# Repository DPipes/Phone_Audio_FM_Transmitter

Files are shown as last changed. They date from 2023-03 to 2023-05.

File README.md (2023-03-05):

# Phone Audio FM Transmitter

A device that connects to a smartphone over Bluetooth and transmits the phone's audio over FM. This allows users to listen to their phones over the radio of cars that do not otherwise offer that functionality. In contrast to similar devices on the market, this can scan the FM band and identify an open channel to broadcast on so the user only has to set their car radio to the same station.

This is an electrical engineering senior design project for ECE 445 at the University of Illinois - Urbana Champaign

Team Members:
 - James W.
 - Madigan C.
 - Dan P.

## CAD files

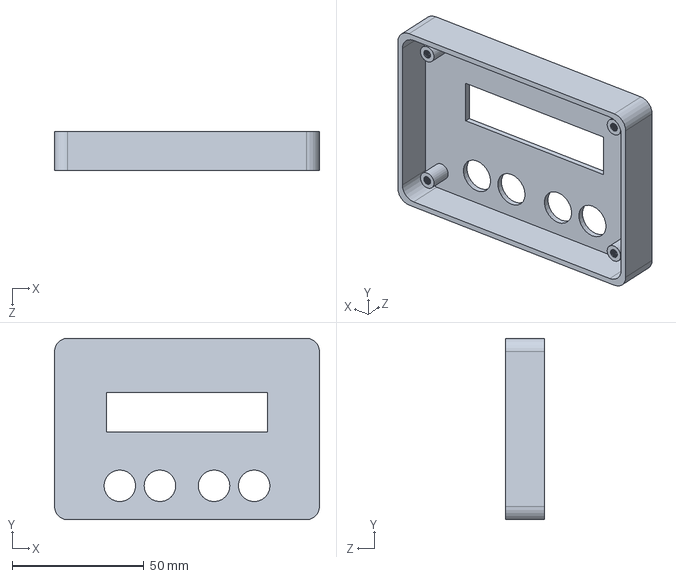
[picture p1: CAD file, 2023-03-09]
Case/case-front-rev1.SLDPRT
100.7 x 69.0 x 15.0 mm

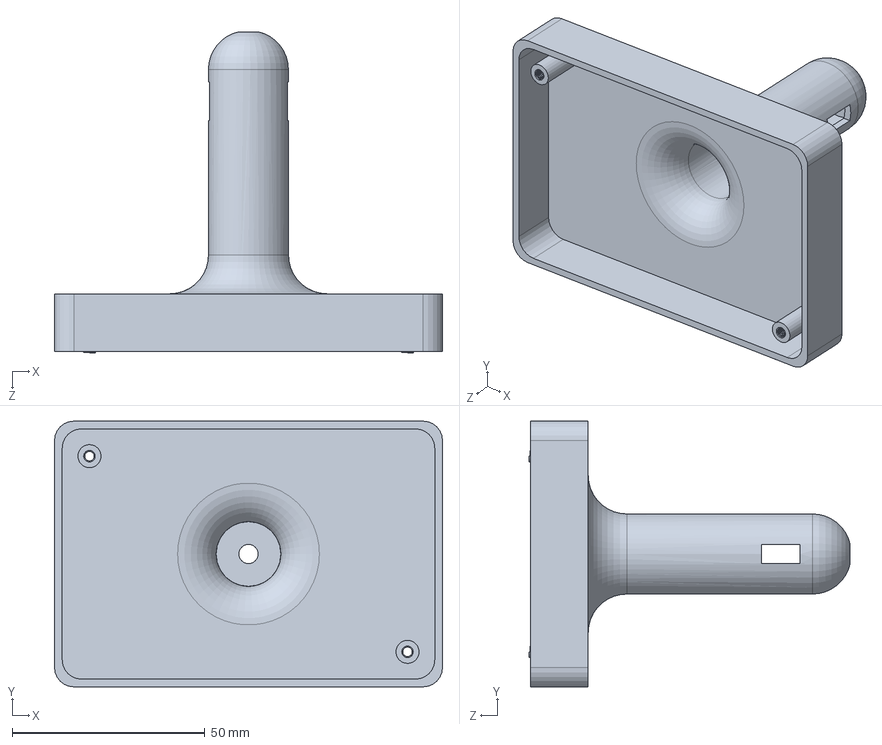
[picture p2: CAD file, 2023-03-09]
Case/case-back-rev1.SLDPRT
100.7 x 69.0 x 83.4 mm

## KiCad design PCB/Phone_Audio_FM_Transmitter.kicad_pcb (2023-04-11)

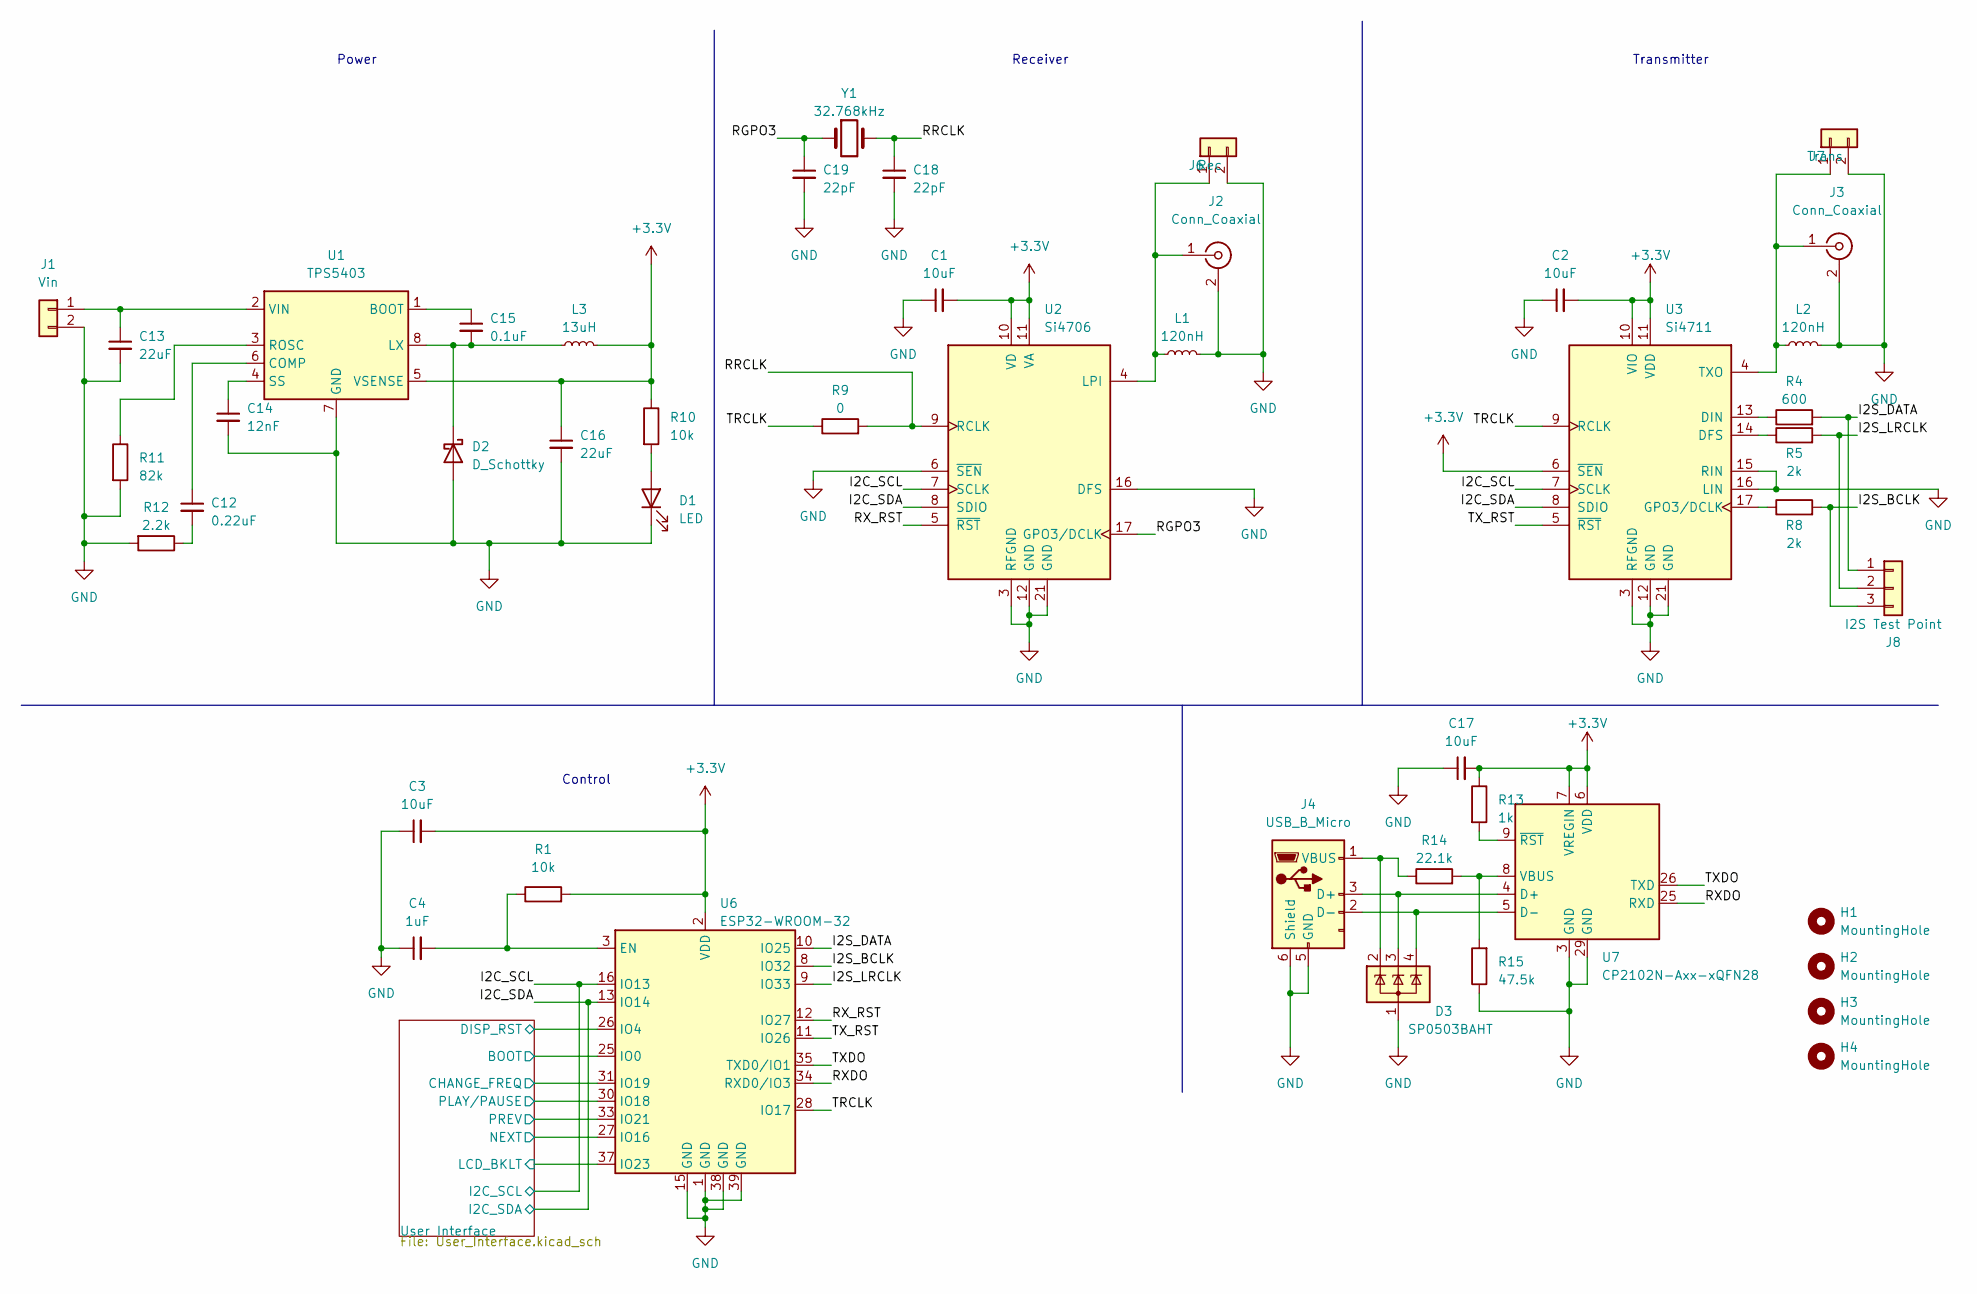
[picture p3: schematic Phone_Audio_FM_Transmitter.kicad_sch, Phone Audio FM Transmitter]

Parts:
C1, C2, C3, C17: 10uF; C_0805_2012Metric_Pad1.18x1.45mm_HandSolder
C4: 1uF; C_0805_2012Metric_Pad1.18x1.45mm_HandSolder
C12: 0.22uF; C_0805_2012Metric_Pad1.18x1.45mm_HandSolder
C13, C16: 22uF; C_0805_2012Metric_Pad1.18x1.45mm_HandSolder
C14: 12nF; C_0805_2012Metric_Pad1.18x1.45mm_HandSolder
C15: 0.1uF; C_0805_2012Metric_Pad1.18x1.45mm_HandSolder
C18, C19: 22pF; C_0805_2012Metric_Pad1.18x1.45mm_HandSolder
D1: LED; LED_1206_3216Metric_Pad1.42x1.75mm_HandSolder
D2: D_Schottky; D_1206_3216Metric_Pad1.42x1.75mm_HandSolder
D3: SP0503BAHT; SOT-143
H1, H2, H3, H4: MountingHole; MountingHole_3.2mm_M3
J1: Vin; Molex_KK-254_AE-6410-02A_1x02_P2.54mm_Vertical
J2, J3: Conn_Coaxial; SMA_Amphenol_132134-10_Vertical
J4: USB_B_Micro; USB_Micro-B_Amphenol_10118194_Horizontal
J6: Rec; Molex_KK-254_AE-6410-02A_1x02_P2.54mm_Vertical
J7: Trans; Molex_KK-254_AE-6410-02A_1x02_P2.54mm_Vertical
J8: I2S Test Point; Molex_KK-254_AE-6410-03A_1x03_P2.54mm_Vertical
L1, L2: 120nH; L_0805_2012Metric_Pad1.15x1.40mm_HandSolder
L3: 13uH; L_0805_2012Metric_Pad1.15x1.40mm_HandSolder
R1, R10: 10k; R_0805_2012Metric_Pad1.20x1.40mm_HandSolder
R4: 600; R_0805_2012Metric_Pad1.20x1.40mm_HandSolder
R5, R8: 2k; R_0805_2012Metric_Pad1.20x1.40mm_HandSolder
R9: 0; R_0805_2012Metric_Pad1.20x1.40mm_HandSolder
R11: 82k; R_0805_2012Metric_Pad1.20x1.40mm_HandSolder
R12: 2.2k; R_0805_2012Metric_Pad1.20x1.40mm_HandSolder
R13: 1k; R_0805_2012Metric_Pad1.20x1.40mm_HandSolder
R14: 22.1k; R_0805_2012Metric_Pad1.20x1.40mm_HandSolder
R15: 47.5k; R_0805_2012Metric_Pad1.20x1.40mm_HandSolder
U1: TPS5403; SOIC-8_3.9x4.9mm_P1.27mm
U2: Si4706; SiliconLabs_QFN-20-1EP_3x3mm_P0.5mm_EP1.8x1.8mm
U3: Si4711; SiliconLabs_QFN-20-1EP_3x3mm_P0.5mm_EP1.8x1.8mm
U6: ESP32-WROOM-32
U7: CP2102N-Axx-xQFN28; QFN-28-1EP_5x5mm_P0.5mm_EP3.35x3.35mm
Y1: 32.768kHz; Crystal_SMD_2012-2Pin_2.0x1.2mm_HandSoldering

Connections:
+3.3V: C1.2, C2.2, C3.2, C16.1, C17.2, L3.2, R1.2, R10.1, R13.1, U1.5 (VSENSE), U2.10 (VD), U2.11 (VA), U3.6 (~SEN), U3.10 (VIO), U3.11 (VDD), U6.2 (VDD), U7.6 (VDD), U7.7 (VREGIN); also elsewhere on the board
/I2C_SCL: U2.7 (SCLK), U3.7 (SCLK), U6.16 (IO13); also elsewhere on the board
/I2C_SDA: U2.8 (SDIO), U3.8 (SDIO), U6.13 (IO14); also elsewhere on the board
/I2S_BCLK: J8.3, R8.2, U6.8 (IO32)
/I2S_DATA: J8.1, R4.2, U6.10 (IO25)
/I2S_LRCLK: J8.2, R5.2, U6.9 (IO33)
/RGPO3: C19.1, U2.17 (GPO3/DCLK), Y1.1
/RRCLK: C18.1, R9.2, U2.9 (RCLK), Y1.2
/RXDO: U6.34 (RXD0/IO3), U7.25 (RXD)
/RX_RST: U2.5 (~RST), U6.12 (IO27)
/TRCLK: R9.1, U3.9 (RCLK), U6.28 (IO17)
/TXDO: U6.35 (TXD0/IO1), U7.26 (TXD)
/TX_RST: U3.5 (~RST), U6.11 (IO26)
/User Interface/BOOT: U6.25 (IO0); also elsewhere on the board
/User Interface/CHANGE_FREQ: U6.31 (IO19); also elsewhere on the board
/User Interface/DISP_RST: U6.26 (IO4); also elsewhere on the board
/User Interface/LCD_BKLT: U6.37 (IO23); also elsewhere on the board
/User Interface/NEXT: U6.27 (IO16); also elsewhere on the board
/User Interface/PLAY/PAUSE: U6.30 (IO18); also elsewhere on the board
/User Interface/PREV: U6.33 (IO21); also elsewhere on the board
GND: C1.1, C2.1, C3.1, C4.1, C13.2, C14.2, C16.2, C17.1, C18.2, C19.2, D1.1 (K), D2.2 (A), D3.1 (A), J1.2, J2.2 (Ext), J3.2 (Ext), J4.5 (GND), J4.6 (Shield), J6.2, J7.2, L1.1, L2.1, R11.2, R12.2, R15.1, U1.7 (GND), U2.3 (RFGND), U2.6 (~SEN), U2.12 (GND), U2.16 (DFS), U2.21 (GND), U3.3 (RFGND), U3.12 (GND), U3.15 (RIN), U3.16 (LIN), U3.21 (GND), U6.1 (GND), U6.15 (GND), U6.38 (GND), U6.39 (GND), U7.3 (GND), U7.29 (GND); also elsewhere on the board
unnamed: C12.2, R12.1
unnamed: D1.2 (A), R10.2
unnamed: C15.2, D2.1 (K), L3.1, U1.8 (LX)
unnamed: C13.1, J1.1, U1.2 (VIN)
unnamed: J2.1 (In), J6.1, L1.2, U2.4 (LPI)
unnamed: J3.1 (In), J7.1, L2.2, U3.4 (TXO)
unnamed: D3.3 (K), J4.3 (D+), U7.4 (D+)
unnamed: D3.4 (K), J4.2 (D-), U7.5 (D-)
unnamed: D3.2 (K), J4.1 (VBUS), R14.1
unnamed: C15.1, U1.1 (BOOT)
unnamed: C12.1, U1.6 (COMP)
unnamed: R11.1, U1.3 (ROSC)
unnamed: C14.1, U1.4 (SS)
unnamed: R5.1, U3.14 (DFS)
unnamed: R4.1, U3.13 (DIN)
unnamed: R8.1, U3.17 (GPO3/DCLK)
unnamed: C4.2, R1.1, U6.3 (EN)
unnamed: R14.2, R15.2, U7.8 (VBUS)
unnamed: R13.2, U7.9 (~RST)

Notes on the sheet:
Control
Transmitter
Power
Receiver

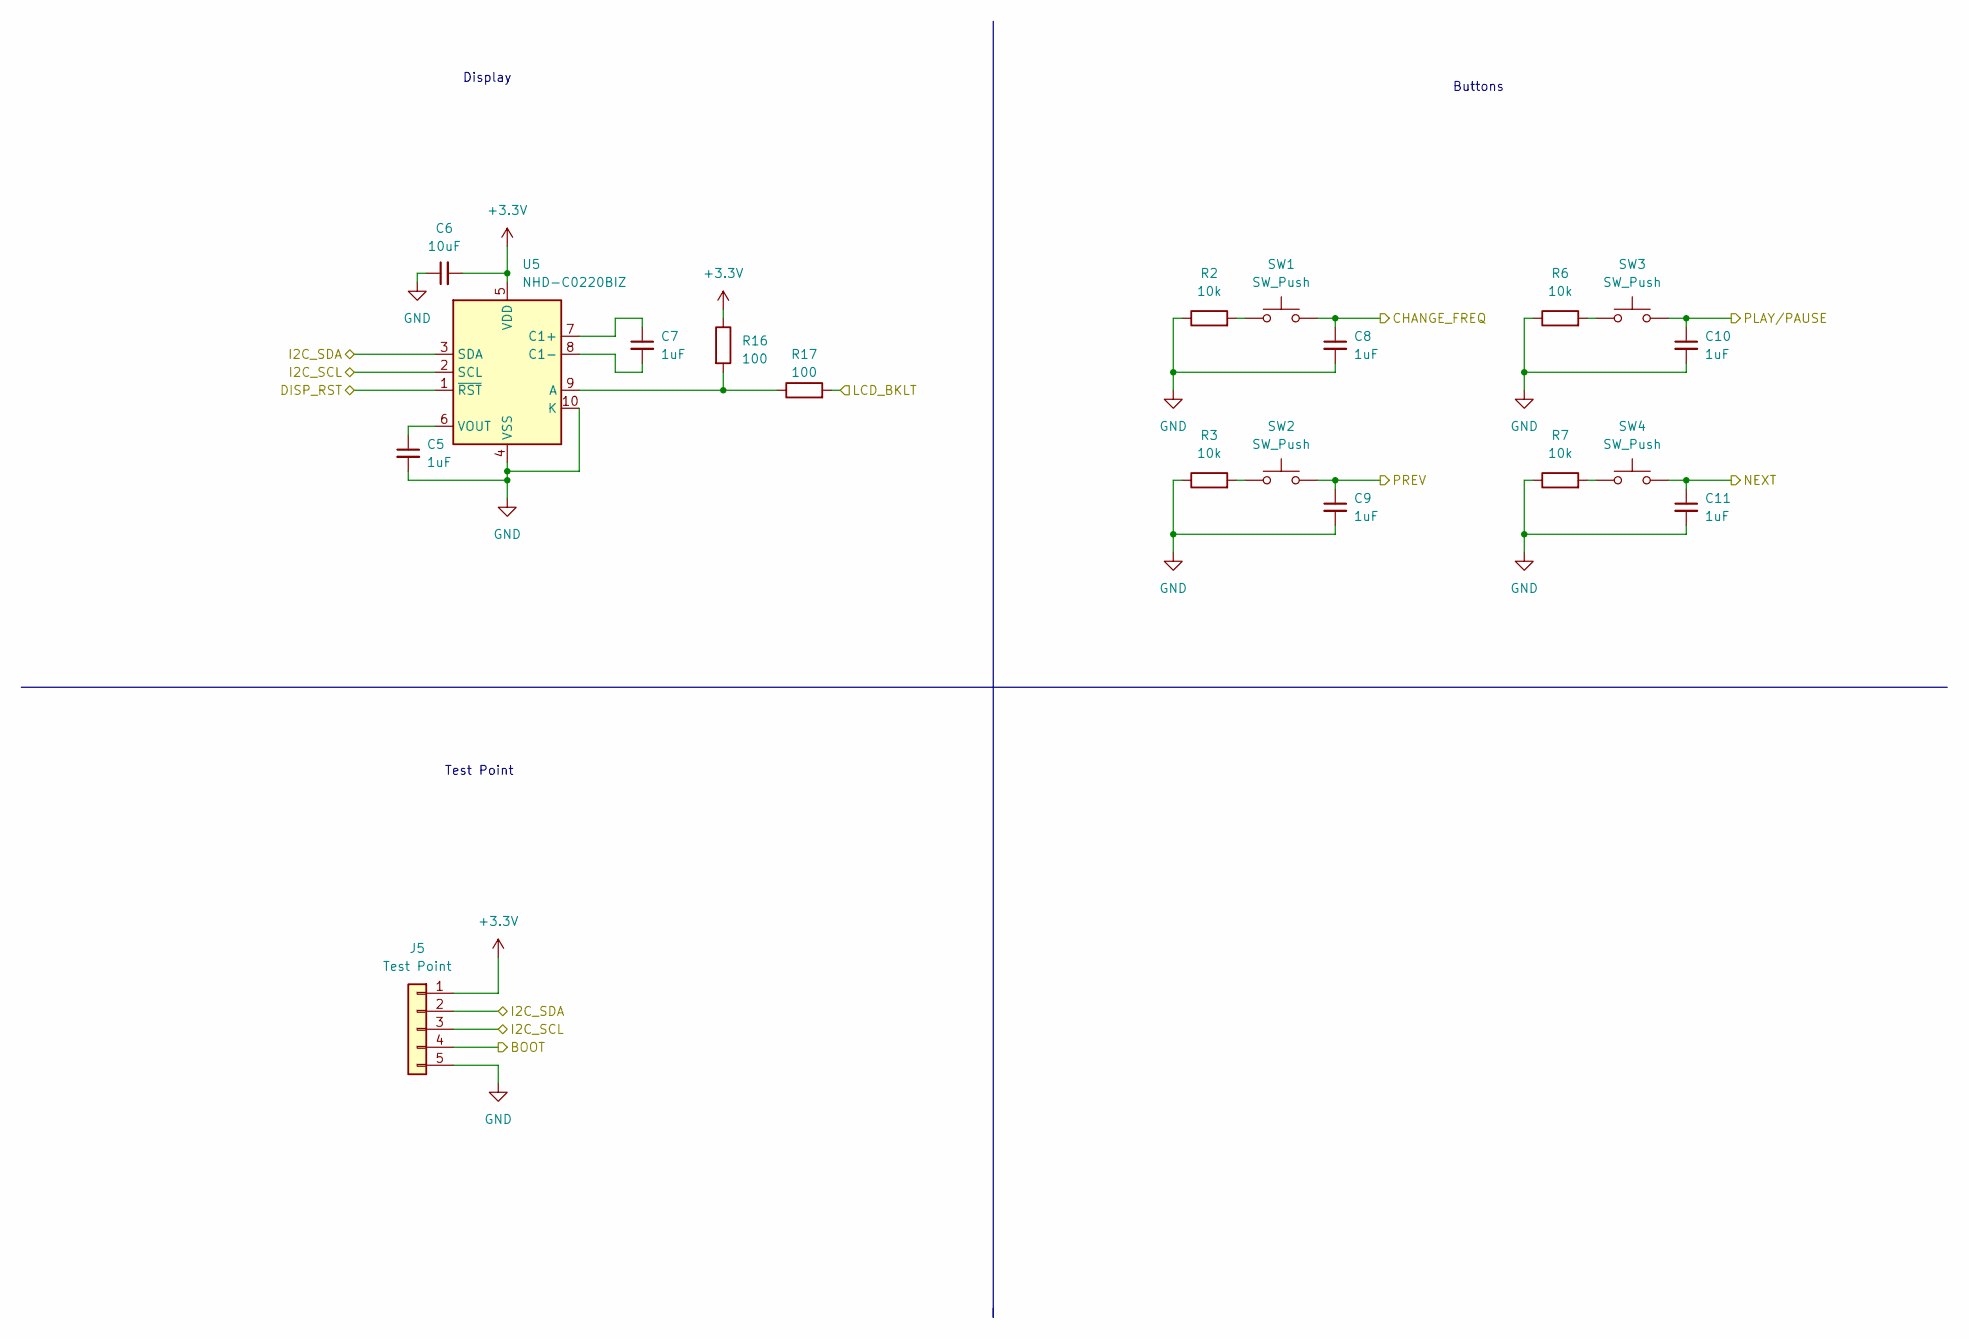
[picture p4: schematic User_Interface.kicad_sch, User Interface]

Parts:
C5, C7, C8, C9, C10, C11: 1uF; C_0805_2012Metric_Pad1.18x1.45mm_HandSolder
C6: 10uF; C_0805_2012Metric_Pad1.18x1.45mm_HandSolder
J5: Test Point; Molex_KK-254_AE-6410-05A_1x05_P2.54mm_Vertical
R2, R3, R6, R7: 10k; R_0805_2012Metric_Pad1.20x1.40mm_HandSolder
R16, R17: 100; R_0805_2012Metric_Pad1.20x1.40mm_HandSolder
SW1, SW2, SW3, SW4: SW_Push; SW_SPST_Omron_B3FS-101xP
U5: NHD-C0220BIZ; NHD-C0220BiZ

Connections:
+3.3V: C6.2, J5.1, R16.1, U5.5 (VDD); also elsewhere on the board
/I2C_SCL: J5.3, U5.2 (SCL); also elsewhere on the board
/I2C_SDA: J5.2, U5.3 (SDA); also elsewhere on the board
/User Interface/BOOT: J5.4; also elsewhere on the board
/User Interface/CHANGE_FREQ: C8.1, SW1.2; also elsewhere on the board
/User Interface/DISP_RST: U5.1 (~RST); also elsewhere on the board
/User Interface/LCD_BKLT: R17.2; also elsewhere on the board
/User Interface/NEXT: C11.1, SW4.2; also elsewhere on the board
/User Interface/PLAY/PAUSE: C10.1, SW3.2; also elsewhere on the board
/User Interface/PREV: C9.1, SW2.2; also elsewhere on the board
GND: C5.2, C6.1, C8.2, C9.2, C10.2, C11.2, J5.5, R2.1, R3.1, R6.1, R7.1, U5.4 (VSS), U5.10 (K); also elsewhere on the board
unnamed: R2.2, SW1.1
unnamed: R3.2, SW2.1
unnamed: R6.2, SW3.1
unnamed: R7.2, SW4.1
unnamed: R16.2, R17.1, U5.9 (A)
unnamed: C7.1, U5.7 (C1+)
unnamed: C7.2, U5.8 (C1-)
unnamed: C5.1, U5.6 (VOUT)

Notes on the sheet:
Display
Test Point
Buttons

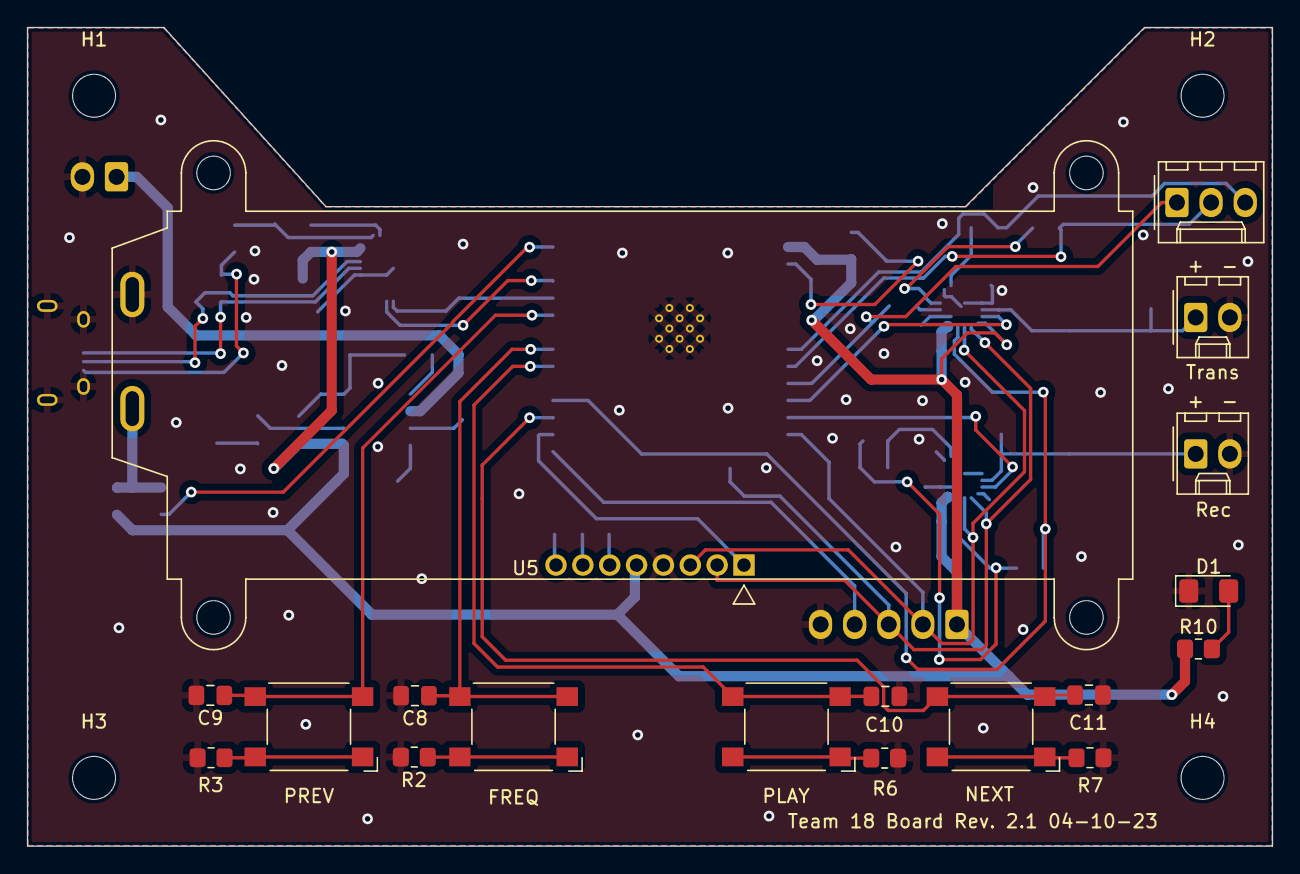
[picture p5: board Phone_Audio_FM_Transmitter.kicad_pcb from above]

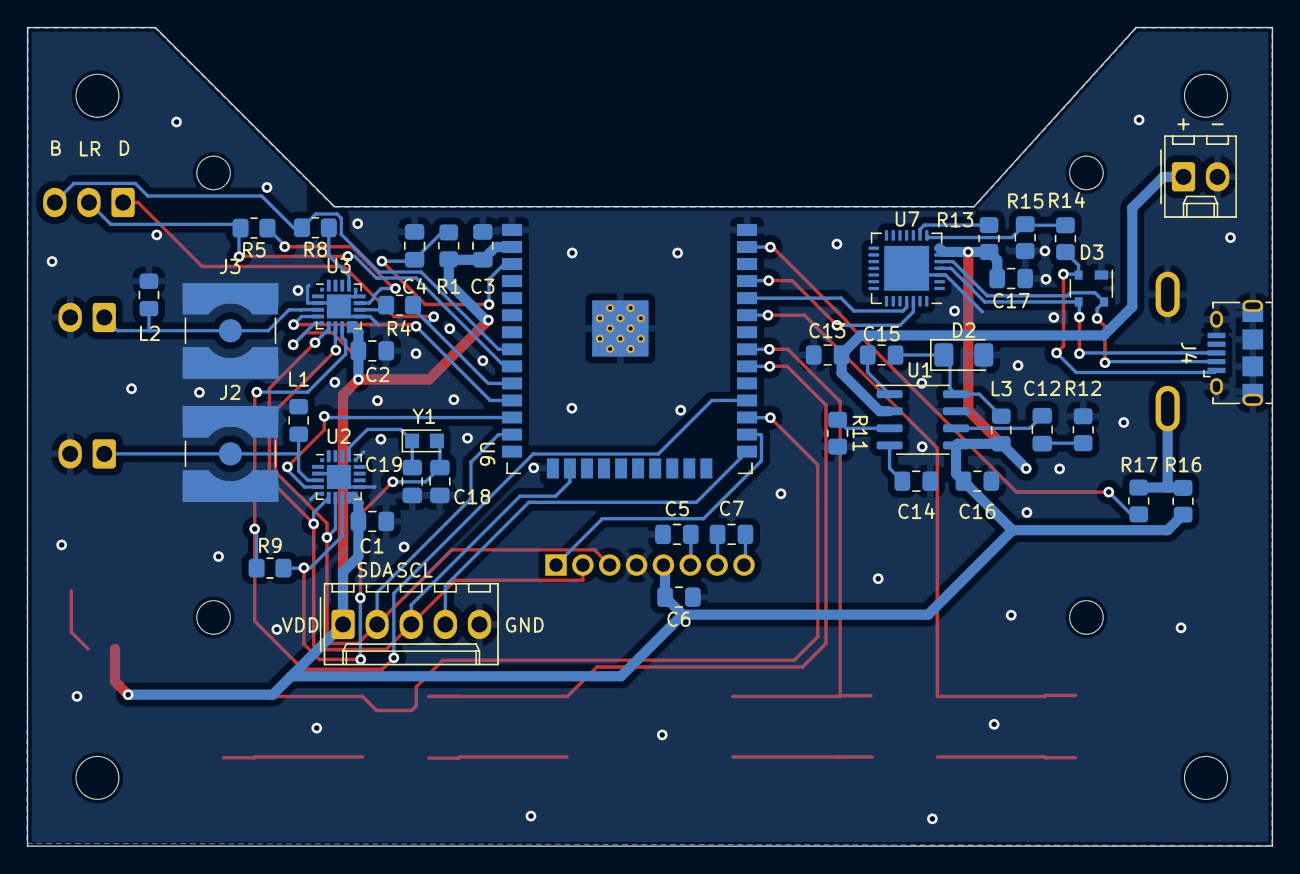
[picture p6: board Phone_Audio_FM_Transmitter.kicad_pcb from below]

Board: 2 copper layers, 92.7 x 61.0 mm, 65 parts (43 on the bottom side), 48 nets.

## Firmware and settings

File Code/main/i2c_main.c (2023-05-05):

#include "i2c_main.h"

void i2c_write_read(uint8_t dev_addr, uint8_t* write_data, size_t write_len, uint8_t* read_data, size_t read_len)
{
    i2c_master_write_read_device(I2C_MASTER_NUM, dev_addr, write_data, write_len, read_data, read_len, I2C_MASTER_TIMEOUT_MS / portTICK_PERIOD_MS);
}

void i2c_register_read(uint8_t dev_addr, uint8_t reg_addr, uint8_t* data, size_t len)
{
    /* Write register address and read response of desired length */
    i2c_master_write_read_device(I2C_MASTER_NUM, dev_addr, &reg_addr, 1, data, len, I2C_MASTER_TIMEOUT_MS / portTICK_PERIOD_MS);
}

void i2c_address_only_read(uint8_t dev_addr, uint8_t* data, size_t len)
{
    /* read from a device after writing only the address to the bus
    will only work if the device doesn't nedd a register address */
    i2c_master_read_from_device(I2C_MASTER_NUM, dev_addr, data, len, I2C_MASTER_TIMEOUT_MS / portTICK_PERIOD_MS);
}

void i2c_register_write(uint8_t dev_addr, uint8_t reg_addr, uint8_t* data, size_t len)
{
    /* Initialize write buffer with register address followed by data to write */
    uint8_t* write_buf = (uint8_t*)malloc(sizeof(uint8_t) * (len + 1));

    write_buf[0] = reg_addr;
    for (int i = 0; i < len; i++) {
        write_buf[i + 1] = data[i];
    }

    /* Write data */
    i2c_master_write_to_device(I2C_MASTER_NUM, dev_addr, write_buf, len + 1, I2C_MASTER_TIMEOUT_MS / portTICK_PERIOD_MS);

    /* Release buffer */
    free(write_buf);
}

void i2c_init(void)
{
    int i2c_master_port = I2C_MASTER_NUM;

    i2c_config_t conf = {
        .mode = I2C_MODE_MASTER,
        .sda_io_num = I2C_MASTER_SDA_IO,
        .scl_io_num = I2C_MASTER_SCL_IO,
        .sda_pullup_en = GPIO_PULLUP_ENABLE,
        .scl_pullup_en = GPIO_PULLUP_ENABLE,
        .master.clk_speed = I2C_MASTER_FREQ_HZ,
    };

    i2c_param_config(i2c_master_port, &conf);

    i2c_driver_install(i2c_master_port, conf.mode, I2C_MASTER_RX_BUF_DISABLE, I2C_MASTER_TX_BUF_DISABLE, 0);
}

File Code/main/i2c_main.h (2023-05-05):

#include <stdio.h>
#include "esp_log.h"
#include "driver/i2c.h"

#define I2C_MASTER_SCL_IO           13                          /*!< GPIO number used for I2C master clock */
#define I2C_MASTER_SDA_IO           14                         /*!< GPIO number used for I2C master data  */
#define I2C_MASTER_NUM              0                          /*!< I2C master i2c port number, the number of i2c peripheral interfaces available will depend on the chip */
#define I2C_MASTER_FREQ_HZ          300000                     /*!< I2C master clock frequency */
#define I2C_MASTER_TX_BUF_DISABLE   0                          /*!< I2C master doesn't need buffer */
#define I2C_MASTER_RX_BUF_DISABLE   0                          /*!< I2C master doesn't need buffer */
#define I2C_MASTER_TIMEOUT_MS       1000

/**
 * @brief write a specified nubmer of bytes to the I2C bus, then
 * immediately read a specified nubmer of bytes from the I2C bus
 *
 * @param dev_addr Address of the I2C slave device to read from
 * @param write_data array of bytes to write to the bus
 * @param write_len number of bytes to write to the bus
 * @param read_data Buffer to hold read data
 * @param read_len Number of bytes in the read_data array
 */
void i2c_write_read(uint8_t dev_addr, uint8_t* write_data, size_t write_len, uint8_t* read_data, size_t read_len);

/**
 * @brief Read a sequence of bytes from the I2C bus from device address and register address
 *
 * @param dev_addr Address of the I2C slave device to read from
 * @param reg_addr Address of the register to read from on the slave device
 * @param data Buffer to hold read data
 * @param len Number of bytes in the data array
 */
void i2c_register_read(uint8_t dev_addr, uint8_t reg_addr, uint8_t* data, size_t len);

/**
 * @brief Read a sequence of bytes from the I2C bus from device address only
 *
 * @param dev_addr Address of the I2C slave device to read from
 * @param data Buffer to hold read data
 * @param len Number of bytes in the data array
 */
void i2c_address_only_read(uint8_t dev_addr, uint8_t* data, size_t len);

/**
 * @brief Write a sequence of bytes to the I2C bus
 *
 * @param dev_addr Address of the I2C slave device to write to
 * @param reg_addr Address of the register to write to on the slave device
 * @param data Array of bytes to send on the bus
 * @param len Number of bytes in the data array
 */
void i2c_register_write(uint8_t dev_addr, uint8_t reg_addr, uint8_t* data, size_t len);

/**
 * @brief Write a single byte to the I2C bus
 *
 * @param dev_addr Address of the I2C slave device to write to
 * @param data Array of bytes to send on the bus
 */
void i2c_write_byte(uint8_t dev_addr, uint8_t data);

/**
 * @brief i2c master initialization
 */
void i2c_init(void);

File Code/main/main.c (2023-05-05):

#include <stdio.h>
#include <string.h>
#include "freertos/FreeRTOS.h"
#include "freertos/task.h"
#include "driver/gpio.h"
#include "driver/i2c.h"
#include "esp_log.h"
#include "sdkconfig.h"
#include "i2c_main.h"
#include "display.h"
#include "blt.h"
#include "rec.h"
#include "trans.h"
#include "fm.h"
#include "fm_ic.h"

void app_main(void)
{
    /* Initialize */
    i2c_init();
    rclk_init();
    blt_init();
    disp_init();
    fm_init();

    /* Main loop */
    while (true) {
        /* Increment receiver frequency */
        step_freq();

        /* Check if frequency should be changed */
        if (check_buttons() == CHANGE_FREQ_PIN) change_freq();
    }
}

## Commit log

2023-03-05 Added datasheets and PCB files
    [project.kicad_pcb, project.kicad_sch, untitled.kicad_sch]
2023-03-05 Added voltage regulator components to finish schematic
    [Phone_Audio_FM_Transmitter.kicad_sch]
2023-03-05 Added first revision of layout. Needs antennae and possibly I2S test points.
    [Phone_Audio_FM_Transmitter.kicad_pcb, Phone_Audio_FM_Transmitter.kicad_sch]
2023-03-05 Updated design rules for PCBWay
2023-03-05 Generated Gerber files
    [Phone_Audio_FM_Transmitter-B_Cu.gbl, Phone_Audio_FM_Transmitter-B_Mask.gbs, Phone_Audio_FM_Transmitter-B_Silkscreen.gbo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]
2023-03-06 Finished Rev. 1 layout with Gerber files
    [Phone_Audio_FM_Transmitter-B_Cu.gbl, Phone_Audio_FM_Transmitter-B_Paste.gbp, Phone_Audio_FM_Transmitter-B_Silkscreen.gbo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]
2023-03-09 Case Revision 1
    [case-back-rev1.SLDPRT, case-front-rev1.SLDPRT]
2023-03-15 added a couple datasheets
2023-03-15 Reorganized some files
    [case-back-rev1.SLDPRT, case-front-rev1.SLDPRT]
2023-03-22 Added basic software framework
2023-03-27 Changed microcontroller from ESP32-S3 to ESP32 and added UART bridge
    [Phone_Audio_FM_Transmitter.kicad_sch, User_Interface.kicad_sch]
2023-03-28 added document explaining how things work + containing my questions, ppartially wrote the powerup function
2023-03-29 Completed PCB Rev 2. Changed microcontroller to ESP32-WROOM-32, added UART bridge, removed button pull-up resistors, added I2S test point, added option to control backlight, and better organized all 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
    [Phone_Audio_FM_Transmitter-B_Cu.gbl, Phone_Audio_FM_Transmitter-B_Mask.gbs, Phone_Audio_FM_Transmitter-B_Paste.gbp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]
2023-03-29 Added resistors to I2S pins on transmitter
    [Phone_Audio_FM_Transmitter-B_Cu.gbl, Phone_Audio_FM_Transmitter-B_Mask.gbs, Phone_Audio_FM_Transmitter-B_Paste.gbp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]
2023-03-29 Added UART bridge datasheet
2023-03-30 added 'i2c_address_only_read' to read from a device on i2c bus using only an address
2023-03-30 added 'i2c_write_read' to the i2c files to allow a write followed by a read because this is the structure of every signle command for transceiver chips
2023-03-30 added 'trans_command' to transmitter files, used that function to write the power_up function
2023-03-30 changed name of power_up fcn and fixed an issue with it
    [trans.c]
2023-04-02 fixed power up, changed write and read, changed send command to include delay
    [trans.c]
2023-04-04 wrote a couple receiver functions
2023-04-11 Added crystal oscillator for receiver IC and RCLK from ESP32 to FM ICs
    [Phone_Audio_FM_Transmitter-B_Cu.gbl, Phone_Audio_FM_Transmitter-B_Mask.gbs, Phone_Audio_FM_Transmitter-B_Paste.gbp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]
2023-04-17 bugs squashed, pins updated
    [display.c, i2c_main.h, main.c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]
2023-04-18 fully working a2dp audio over i2s, limited avrc functionality
    [partitions_bt_sink_example.csv]
2023-04-19 removed conflicting files
    [partitions_bt_sink_example.csv]
2023-04-20 Bluetooth audio -> FM completed
    [partitions_bt_sink_example.csv]
2023-04-29 Changed schematic to reflect final design
    [Phone_Audio_FM_Transmitter.kicad_sch, User_Interface.kicad_sch]
